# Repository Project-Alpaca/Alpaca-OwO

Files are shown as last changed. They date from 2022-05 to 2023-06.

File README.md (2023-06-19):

# Alpaca-OwO

Obtainable w/ rOna I/O board.

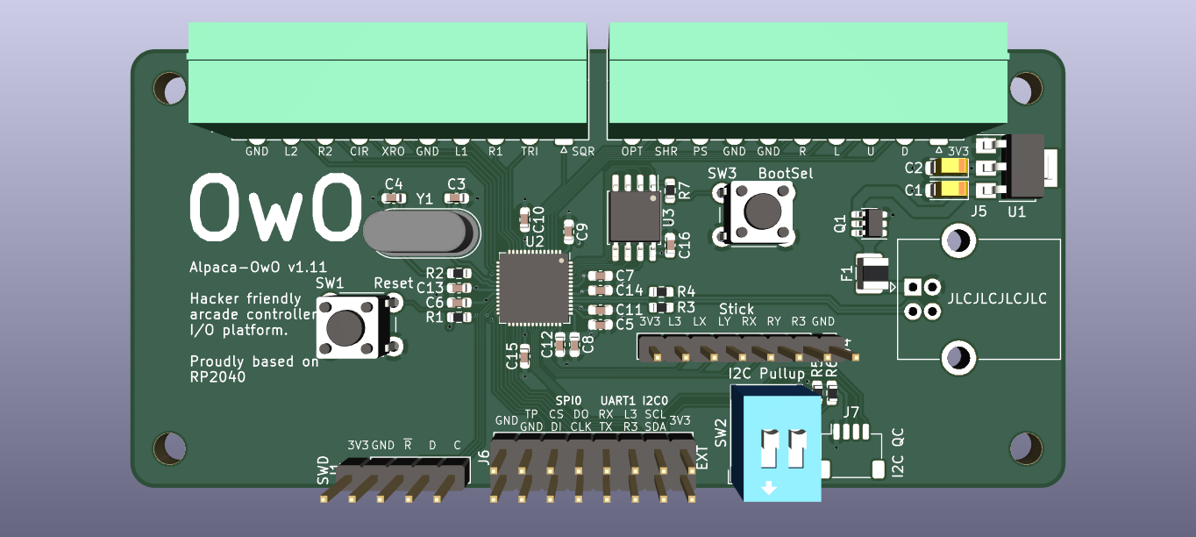
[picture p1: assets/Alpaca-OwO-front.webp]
Alpaca-OwO-front


## Features

- Familiar form factor
- Removable screw terminals makes reconnecting buttons more convenient
  - Tool-less spring terminal option available (when using Phoenix 1952348)
- Rich I/O
  - Analog stick port
  - Simultaneous access to hardware SPI, I2C and basic UART via EXT port
  - SparkFun Qwiic/Adafruit STEMMA-QT compatible I2C quick connect port
  - Possibility to support various proprietary gamepad/joystick interfaces with RP2040 PIO and spare GPIO on EXT port

## Pin assignments

Below is the preferred pin assignment for this board. Note that every pin can be remapped or re-purposed when necessary and this list only serves as a guideline. Still, follow this list when developing firmware if you wish to keep wiring compatibility with other fightstick PCBs and preserve the meaning of the silk screens.

### Pluggable terminal ports

| RP2040 Pin | GP2040 Pin | Label | Purpose |
| --- | --- | ----- | --- |
| 0 | DPad Down | D | D-Button Down |
| 1 | DPad Up | U | D-Button Up |
| 2 | DPad Left | L | D-Button Left |
| 3 | DPad Right | R | D-Button Right |
| 4 | A1 | PS | PS Button |
| 5 | S1 | SHR | Share Button |
| 6 | S2 | OPT | Option Button |
| 7 | B3 | SQR | Square Button |
| 8 | B4 | TRI | Triangle Button |
| 9 | R1 | R1 |R1 Button |
| 10 | L1 | L1 | L1 Button |
| 11 | B1 | XRO | Cross Button |
| 12 | B2 | CIR | Circle Button |
| 13 | R2 | R2 | R2 Button |
| 14 | L2 | L2 | L2 Button |

### Ext port, I2C quick connect and analog stick port

| RP2040 Pin | GP2040 Pin | Label | Purpose |
| --- | --- | ----- | --- |
| 15 | A2 | TP | Touchpad Click Button |
| 16 | - | DI | SPI0 DI |
| 17 | - | CS | SPI0 CS |
| 18 | - | CLK | SPI0 CLK |
| 19 | - | DO | SPI0 DO |
| 20 | - | TX | UART1 TX |
| 21 | - | EXT/RX | UART1 RX |
| 22 | R3 | R3 | R3 Button |
| 23 | L3 | L3 | L3 Button |
| 24 | Display | SDA | I2C0 SDA |
| 25 | Display | SCL | I2C0 SCL |
| 26/ADC0 | - | RY | Analog Stick RY |
| 27/ADC1 | - | Stick/RX | Analog Stick RX |
| 28/ADC2 | - | LY | Analog Stick LY |
| 29/ADC3 | - | LX | Analog Stick LX |

## Terminal block options

Any pluggable terminal block plugs that mate with a Phoenix MINI COMBICON MC terminal block header should be usable with Alpaca-OwO. Notable configurations include the [basic screw terminal (1840447)](https://www.phoenixcontact.com/en-us/products/pcb-plug-mc-1510-st-35-1840447), the [tool-less spring terminal (1939989)](https://www.phoenixcontact.com/en-us/products/pcb-plug-fk-mcp-1510-st-35-1939989) and the [low profile spring terminal (1952348)](https://www.phoenixcontact.com/en-us/products/pcb-plug-fmc-1510-st-35-1952348). Generic replacements of these connectors can be found on Aliexpress or LCSC. Note that the locking variants will not fit and thus not supported.

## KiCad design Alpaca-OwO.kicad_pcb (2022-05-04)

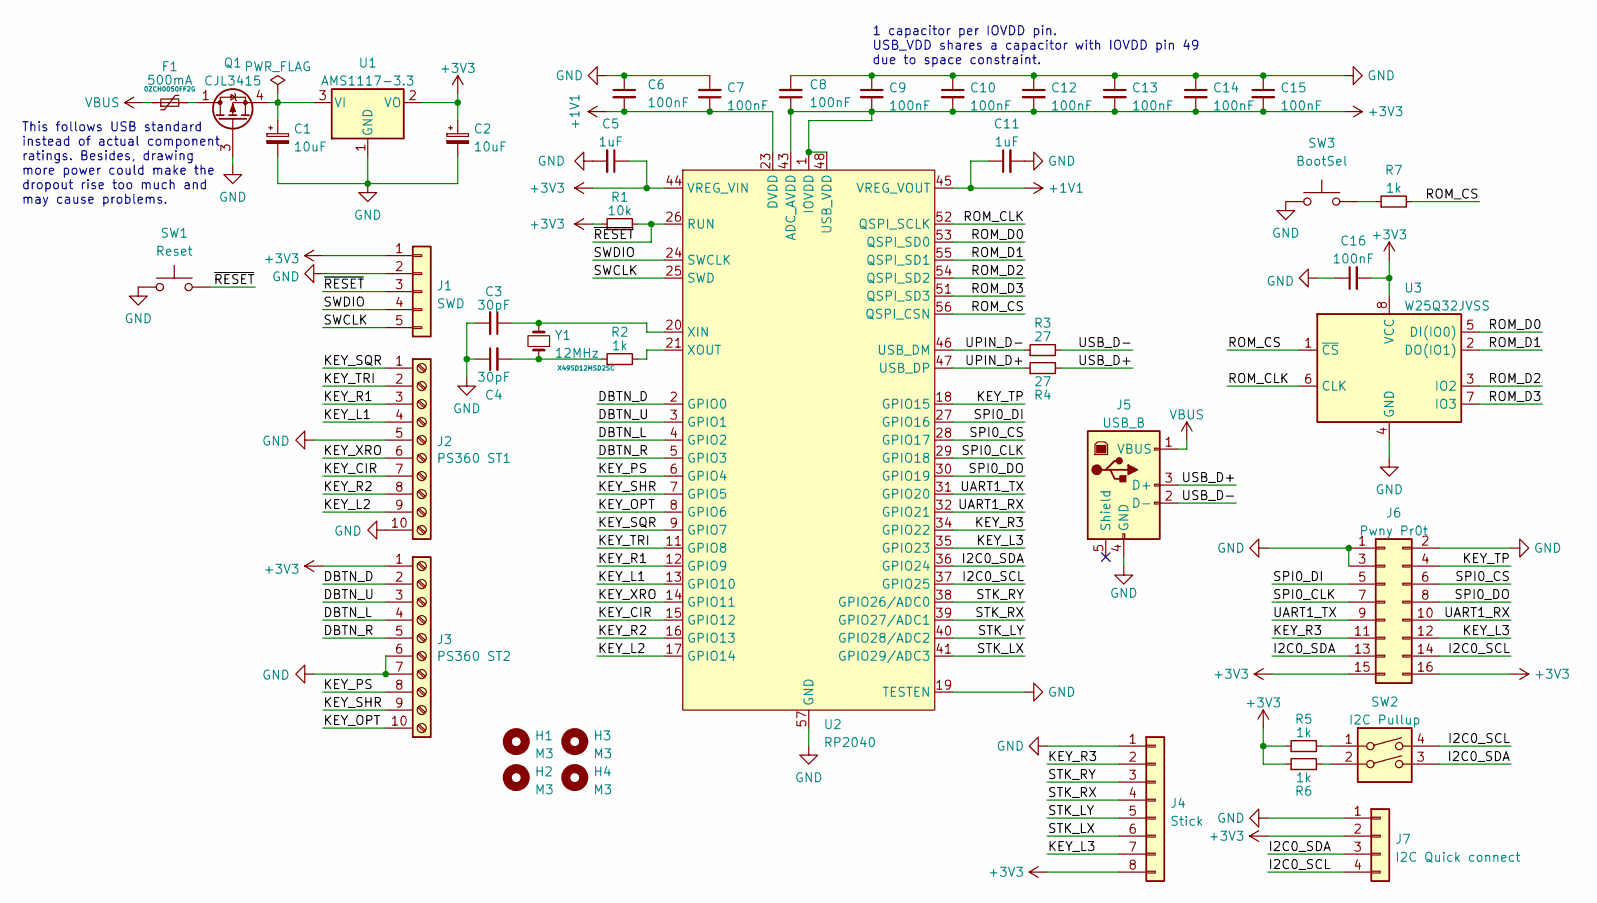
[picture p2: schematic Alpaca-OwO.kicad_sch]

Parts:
C1, C2: 10uF; CP_EIA-3216-18_Kemet-A; JLC CASE-A_3216
C3, C4: 30pF; C_0603_1608Metric; JLC 0603
C5, C11: 1uF; C_0603_1608Metric; JLC 0603
C6, C7, C8, C9, C10, C12, C13, C14, C15, C16: 100nF; C_0603_1608Metric; JLC 0603
F1: 500mA; Fuse_1210_3225Metric; Part Number 0ZCH0050FF2G; LCSC C135348
H1, H2, H3, H4: M3; MountingHole_3.2mm_M3_ISO7380
J1: SWD; PinHeader_1x05_P2.54mm_Vertical; JLC Plugin,P=2.54mm
J2: PS360 ST1; PhoenixContact_MC_1,5_10-G-3.5_1x10_P3.50mm_Horizontal; JLC P=3.5mm
J3: PS360 ST2; PhoenixContact_MC_1,5_10-G-3.5_1x10_P3.50mm_Horizontal; JLC P=3.5mm
J4: Stick; PinHeader_1x08_P2.54mm_Vertical; JLC Plugin,P=2.54mm
J5: USB_B; USB_B_OST_USB-B1HSxx_Horizontal; JLC Plugin
J6: Pwny Pr0t; PinHeader_2x08_P2.54mm_Vertical; JLC Plugin,P=2.54mm
J7: I2C Quick connect; JST_SH_SM04B-SRSS-TB_1x04-1MP_P1.00mm_Horizontal; LCSC C160404
Q1: CJL3415; SOT-23-6; LCSC C114069
R1: 10k; R_0603_1608Metric; JLC 0603
R2, R5, R6, R7: 1k; R_0603_1608Metric; JLC 0603
R3, R4: 27; R_0603_1608Metric; JLC 0603
SW1: Reset; SW_PUSH_6mm; JLC Plugin
SW2: I2C Pullup; SW_DIP_SPSTx02_Slide_9.78x7.26mm_W7.62mm_P2.54mm; JLC Plugin
SW3: BootSel; SW_PUSH_6mm; JLC Plugin
U1: AMS1117-3.3; SOT-223-3_TabPin2; JLC SOT-223
U2: RP2040; QFN-56-1EP_7x7mm_P0.4mm_EP3.2x3.2mm_ThermalVias; JLC QFN-56(7x7)
U3: W25Q32JVSS; SOIC-8_5.23x5.23mm_P1.27mm; JLC SOIC-8_208mil
Y1: 12MHz; Crystal_HC49-4H_Vertical; Part Number X49SD12MSD2SC; JLC HC-49S

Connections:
+1V1: C6.2, C7.1, C11.1, U2.23 (DVDD), U2.45 (VREG_VOUT), U2.50 (DVDD)
+3V3: C2.1, C5.1, C8.1, C9.2, C10.2, C12.2, C13.2, C14.2, C15.2, C16.2, J1.1, J3.1, J4.8, J6.15, J6.16, J7.2, R1.1, R5.1, R6.1, U1.2 (VO), U2.1 (IOVDD), U2.10 (IOVDD), U2.22 (IOVDD), U2.33 (IOVDD), U2.42 (IOVDD), U2.43 (ADC_AVDD), U2.44 (VREG_VIN), U2.48 (USB_VDD), U2.49 (IOVDD), U3.8 (VCC)
/DBTN_D: J3.2, U2.2 (GPIO0)
/DBTN_L: J3.4, U2.4 (GPIO2)
/DBTN_R: J3.5, U2.5 (GPIO3)
/DBTN_U: J3.3, U2.3 (GPIO1)
/I2C0_SCL: J6.14, J7.4, SW2.4, U2.37 (GPIO25)
/I2C0_SDA: J6.13, J7.3, SW2.3, U2.36 (GPIO24)
/KEY_CIR: J2.7, U2.15 (GPIO12)
/KEY_L1: J2.4, U2.13 (GPIO10)
/KEY_L2: J2.9, U2.17 (GPIO14)
/KEY_L3: J4.7, J6.12, U2.35 (GPIO23)
/KEY_OPT: J3.10, U2.8 (GPIO6)
/KEY_PS: J3.8, U2.6 (GPIO4)
/KEY_R1: J2.3, U2.12 (GPIO9)
/KEY_R2: J2.8, U2.16 (GPIO13)
/KEY_R3: J4.2, J6.11, U2.34 (GPIO22)
/KEY_SHR: J3.9, U2.7 (GPIO5)
/KEY_SQR: J2.1, U2.9 (GPIO7)
/KEY_TP: J6.4, U2.18 (GPIO15)
/KEY_TRI: J2.2, U2.11 (GPIO8)
/KEY_XRO: J2.6, U2.14 (GPIO11)
/ROM_CLK: U2.52 (QSPI_SCLK), U3.6 (CLK)
/ROM_CS: R7.2, U2.56 (QSPI_CSN), U3.1 (~CS)
/ROM_D0: U2.53 (QSPI_SD0), U3.5 (DI(IO0))
/ROM_D1: U2.55 (QSPI_SD1), U3.2 (DO(IO1))
/ROM_D2: U2.54 (QSPI_SD2), U3.3 (IO2)
/ROM_D3: U2.51 (QSPI_SD3), U3.7 (IO3)
/SPI0_CLK: J6.7, U2.29 (GPIO18)
/SPI0_CS: J6.6, U2.28 (GPIO17)
/SPI0_DI: J6.5, U2.27 (GPIO16)
/SPI0_DO: J6.8, U2.30 (GPIO19)
/STK_LX: J4.6, U2.41 (GPIO29/ADC3)
/STK_LY: J4.5, U2.40 (GPIO28/ADC2)
/STK_RX: J4.4, U2.39 (GPIO27/ADC1)
/STK_RY: J4.3, U2.38 (GPIO26/ADC0)
/SWCLK: J1.5, U2.25 (SWD)
/SWDIO: J1.4, U2.24 (SWCLK)
/UART1_RX: J6.10, U2.32 (GPIO21)
/UART1_TX: J6.9, U2.31 (GPIO20)
/UPIN_D+: R4.1, U2.47 (USB_DP)
/UPIN_D-: R3.1, U2.46 (USB_DM)
/USB_D+: J5.3 (D+), R4.2
/USB_D-: J5.2 (D-), R3.2
/~RESET: J1.3, R1.2, SW1.1, U2.26 (RUN)
GND: C1.2, C2.2, C3.2, C4.1, C5.2, C6.1, C7.2, C8.2, C9.1, C10.1, C11.2, C12.1, C13.1, C14.1, C15.1, C16.1, J1.2, J2.5, J2.10, J3.6, J3.7, J4.1, J5.4 (GND), J6.1, J6.2, J6.3, J7.1, Q1.3 (G), SW1.2, SW3.2, U1.1 (GND), U2.19 (TESTEN), U2.57 (GND), U3.4 (GND)
unnamed: C1.1, Q1.4 (S), U1.3 (VI)
unnamed: C3.1, U2.20 (XIN), Y1.2
unnamed: C4.2, R2.1, Y1.1
unnamed: F1.2, Q1.1 (D), Q1.2 (D), Q1.5 (D), Q1.6 (D)
unnamed: R2.2, U2.21 (XOUT)
unnamed: R5.2, SW2.1
unnamed: R6.2, SW2.2
unnamed: R7.1, SW3.1
VBUS: F1.1, J5.1 (VBUS)

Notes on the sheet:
This follows USB standard instead of actual component ratings. Besides, drawing more power could make the dropout rise too much and may cause problems.
1 capacitor per IOVDD pin. USB_VDD shares a capacitor with IOVDD pin 49 due to space constraint.

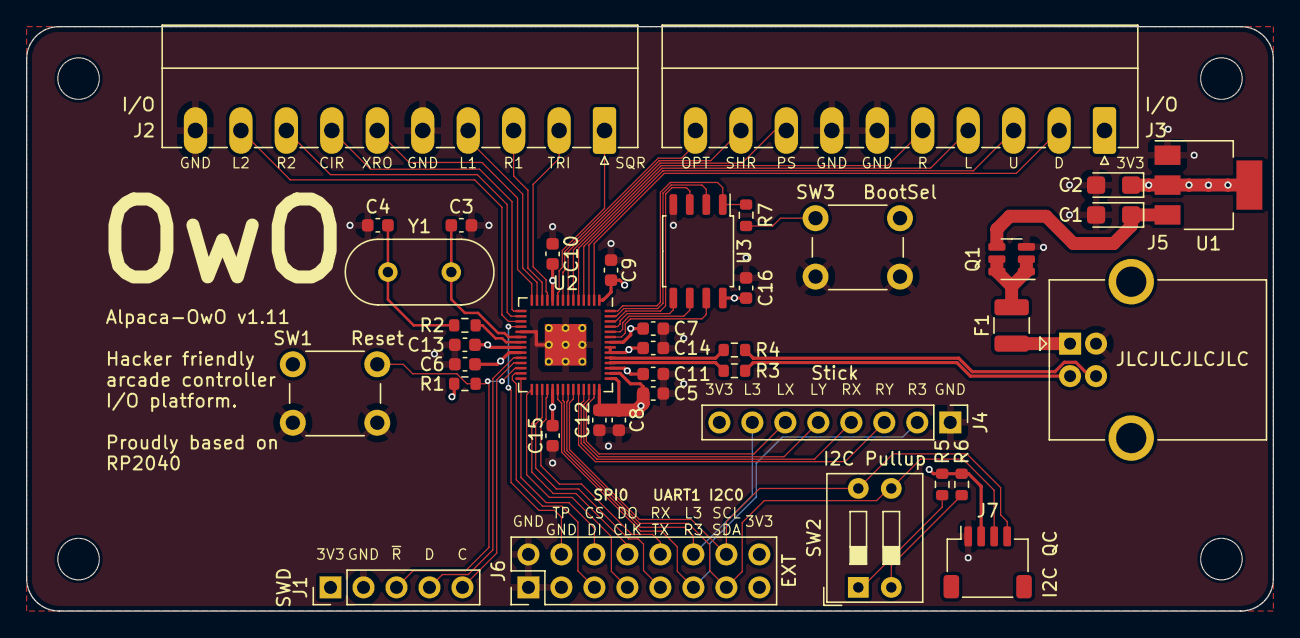
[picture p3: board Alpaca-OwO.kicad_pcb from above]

Board: 4 copper layers, 96.0 x 45.0 mm, 43 parts (0 on the bottom side), 55 nets.

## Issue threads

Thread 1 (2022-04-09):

v1.01 Checklist

dogtopus, 2022-04-09:
- [x] Move J2 and J3 1mm towards outside to get better connector mating
- [x] C10's trace width does not match the rest. Change it.
- [x] Recheck the push button switch footprint as it might not be the generic one
- [x] (Maybe) swap the inner 3V3 and GND plane so important parts will all sit directly on top of the GND plane
- [x] Possibly switch the 1V1 bridge to a inner plane for better inrush current capability
- [x] Too many changes to the component placement. Reroute everything.
- [x] PCBA planning (Priority: RP2040 and surrounding > smaller SMD components > bigger SMD components > THT components) (bonus mark for full JLCPCBA possibility. Fuse will be hard but with digikey ordering feature not impossible?)
- [x] Maybe also change the board to exact PS360 size?
- [x] ~~MadCatz Quick Connect port? (maybe need to move things around a bit. Routing-wise should have minimal problem if we can flip the J3 traces up)~~ Can be added but might needs to be vertically placed due to the current topology.

dogtopus, 2022-04-14:
Bumped to v1.10 since it was more change than initially planned.

Closed 2022-04-14.

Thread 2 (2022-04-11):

Arduino-mbed core porting

dogtopus, 2022-04-11:
This is specifically for the 32Mib ROM used on OwO. Regular Pico only has 16Mib and there's an Arduino variant that uses 128. Both doesn't fit OwO perfectly. It would be better to split the region as 3MiB for code and 1MiB as NVRAM for persistent states and keys, although using stock Arduino-mbed directly and have a 2MiB/2MiB cut is also acceptable.

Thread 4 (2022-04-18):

Route 5V power to EXT port

dogtopus, 2022-04-18:
Currently the board has 3.3V rail only and 5V power requires bulging a wire from the regulator input pin to the sub circuit board that uses it. Route 5v to EXT would be a much cleaner alternative.

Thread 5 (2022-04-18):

Use standard SWD header instead of the Cypress KitProg style one

dogtopus, 2022-04-18:
Self explanatory.

Either the "low profile" but expensive connector or the full sized one. Note that the "low profile" is mostly a lie if it's mated with a full sized plug and the clearance has to be made anyway.

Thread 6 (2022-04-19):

Manufacturability improvements

dogtopus, 2022-04-19:
- [ ] Avoid 45 degree bends on some of the pads (curved pads like 2.54mm pin THs are probably fine but not on rectangular pads)
- [ ] Bump the trace width to 0.15mm
    - Might need to replace some components to 0402. If this is the case, use HandSoldering footprint for them. This will increase the length but should still free up some spaces for routing traces between components.

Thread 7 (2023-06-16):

SWD pins are backwards

dogtopus, 2023-06-16:
The SWCLK/SWDIO pins are routed backwards.

This likely will be a wontfix since v2 will likely have a different SWD port connector.

dogtopus, 2023-06-20:
This is actually just a labeling issue. The pins themselves are not backwards.

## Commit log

2022-03-05 Initial commit
    First schematic done. PnR WIP.
    [Alpaca-OwO.kicad_pcb, Alpaca-OwO.kicad_sch]
2022-03-05 Coarse placement
    [Alpaca-OwO.kicad_pcb, Alpaca-OwO.kicad_sch]
2022-03-07 Routing checkpoint
    [Alpaca-OwO.kicad_pcb, Alpaca-OwO.kicad_sch]
2022-03-08 First PnR attempt done.
    [Alpaca-OwO.kicad_pcb]
2022-03-08 More ground vias.
    [Alpaca-OwO.kicad_pcb]
2022-03-08 Fix various issues.
    - USB DM/DP are reversed.
    - Minimum via OD for JLC should be 0.45mm (technically 0.4mm is also accepted but with a big cost penalty).
    [Alpaca-OwO.kicad_pcb, Alpaca-OwO.kicad_sch]
2022-03-08 Add metadata.
    [Alpaca-OwO.kicad_pcb, Alpaca-OwO.kicad_sch]
2022-04-11 V1.01 rework.
    [Alpaca-OwO.kicad_pcb, Alpaca-OwO.kicad_sch]
2022-04-12 Add some PCBA info.
    [Alpaca-OwO.kicad_sch]
2022-04-13 Flip I2C traces up and some general cleanups
    [Alpaca-OwO.kicad_pcb, Alpaca-OwO.kicad_sch]
2022-04-13 V1.10 PCB
    Change the via size to be 0.55/0.3 so the annular ring width stay consistent with JLC's design rule.
    [Alpaca-OwO.kicad_pcb, Alpaca-OwO.kicad_sch]
2022-04-13 Minor track tuning.
    [Alpaca-OwO.kicad_pcb]
2022-04-14 Import LCSC parts info for all components except pin headers.
    [Alpaca-OwO.kicad_sch]
2022-04-14 Set screw holes as do not include
    [Alpaca-OwO.kicad_sch]
2022-04-14 Add more GND vias near components. Update README.
    [Alpaca-OwO.kicad_pcb]
2022-04-17 v1.11
    Fixed an issue where the analog stick port does not follow the Brook pinout.
    No PCB routing was changed but the pin assignment for stick axis and L3/R3 buttons are now mirrored. Refer to README for the new pinout.
    [Alpaca-OwO.kicad_pcb, Alpaca-OwO.kicad_sch]
2022-05-04 Update silkscreen
    [Alpaca-OwO.kicad_pcb]
2023-06-19 Add more detailed pin assignment info to README
